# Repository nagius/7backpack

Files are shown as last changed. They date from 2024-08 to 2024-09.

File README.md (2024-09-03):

# 7Backpack

7Backpack is a shift register based led driver similar to [SparkFun Large Digit Driver](https://www.sparkfun.com/products/13279) but with a nicer form factor.

It has been designed to fit directly at the back of common anode 7-segments displays. Four sizes are supported : 1.5" (15101BS), 1.8" (18011BH), 2.3" (23011BH) and 3" (30101BS).

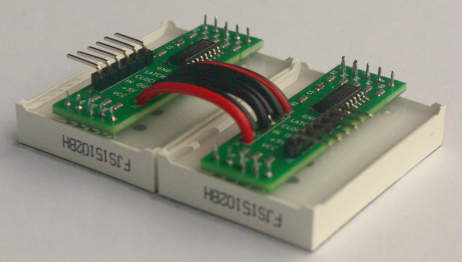
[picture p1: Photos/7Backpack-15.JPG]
1.5"
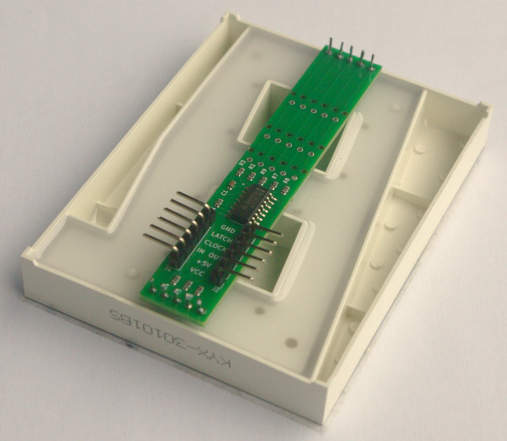
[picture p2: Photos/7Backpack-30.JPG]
3"
Board  

## Features

This board is functionnaly identical to SparkFun Large Digit Driver. Exact same code found at [Spakfun tutorial](https://learn.sparkfun.com/tutorials/large-digit-driver-hookup-guide/all) can be used without any modification.

The size of the board can be adjusted to match the size of the display. The PCB has pre-cut lines to snap unneeded pieces of the board.

## Manufacturing

See directory `Gerber/` for production files and bill of materials.

## License

Copyleft 2024 - Nicolas AGIUS

Creative Commons - Attribution-NonCommercial-ShareAlike 4.0 International (CC BY-NC-SA 4.0)

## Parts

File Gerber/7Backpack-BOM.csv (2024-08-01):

Comment | Designator | Footprint | LCSC
100nF | C1 | Capacitor_SMD:C_0603_1608Metric | C14663
10k | R1 | Resistor_SMD:R_0603_1608Metric | C25804
15 | R2,R3,R4,R5,R6,R7,R8 | Resistor_SMD:R_0603_1608Metric | C22810
2k | R9 | Resistor_SMD:R_0603_1608Metric | C22975
TPIC6C596DC | U1 | TPIC6C596DR:SOIC127P600X175-16N | C2872253

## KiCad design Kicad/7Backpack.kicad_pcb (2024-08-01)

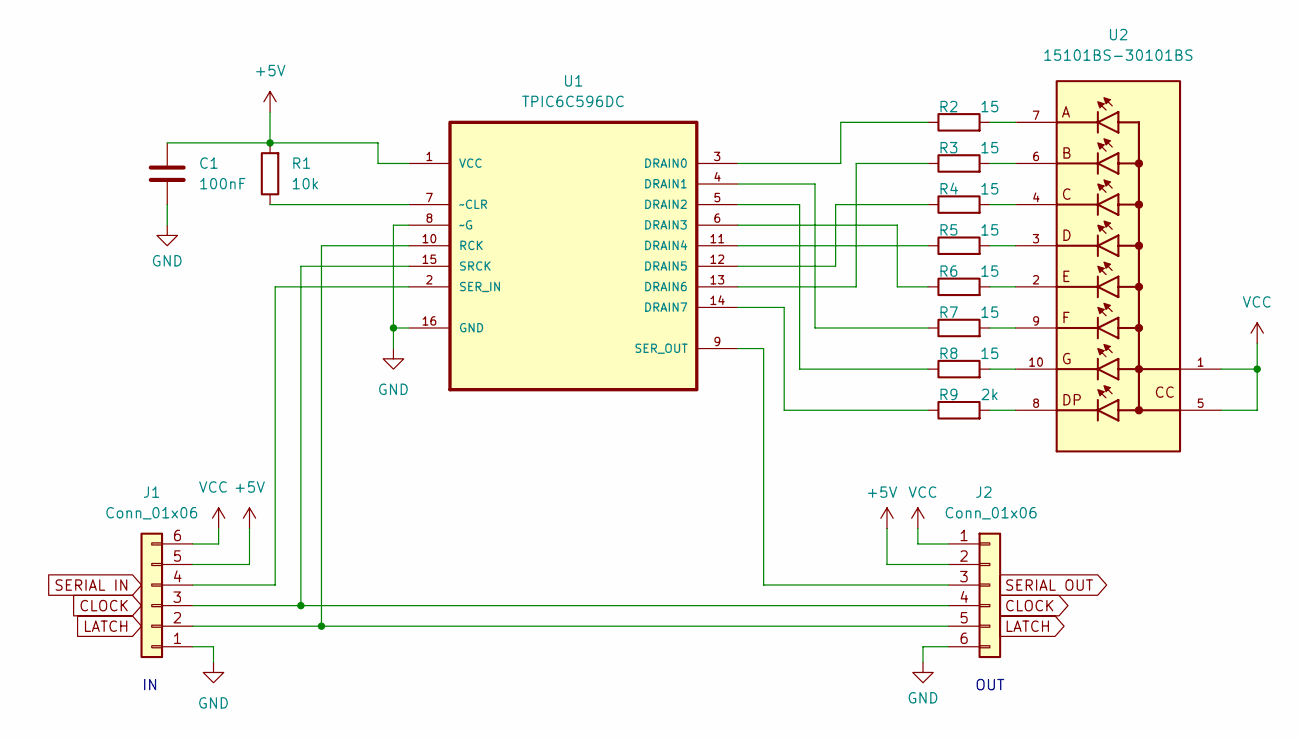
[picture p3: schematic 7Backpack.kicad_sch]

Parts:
C1: 100nF; C_0603_1608Metric; LCSC C14663
J1, J2: Conn_01x06; PinHeader_1x06_P2.54mm_Vertical
R1: 10k; R_0603_1608Metric; LCSC C25804
R2, R3, R4, R5, R6, R7, R8: 15; R_0603_1608Metric; LCSC C22810
R9: 2k; R_0603_1608Metric; LCSC C22975
U1: TPIC6C596DC; SOIC127P600X175-16N; LCSC C2872253
U2: 15101BS-30101BS

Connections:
+5V: C1.1, J1.5, J2.2, R1.2, U1.1 (VCC)
GND: C1.2, J1.1, J2.6, U1.8 (~G), U1.16 (GND)
unnamed: J1.2, J2.5, U1.10 (RCK)
unnamed: J1.3, J2.4, U1.15 (SRCK)
unnamed: J1.4, U1.2 (SER_IN)
unnamed: J2.3, U1.9 (SER_OUT)
unnamed: R1.1, U1.7 (~CLR)
unnamed: R2.1, U1.3 (DRAIN0)
unnamed: R2.2, U2.7
unnamed: R3.1, U1.13 (DRAIN6)
unnamed: R3.2, U2.6
unnamed: R4.1, U1.12 (DRAIN5)
unnamed: R4.2, U2.4
unnamed: R5.1, U1.11 (DRAIN4)
unnamed: R5.2, U2.3
unnamed: R6.1, U1.6 (DRAIN3)
unnamed: R6.2, U2.2
unnamed: R7.1, U1.4 (DRAIN1)
unnamed: R7.2, U2.9
unnamed: R8.1, U1.5 (DRAIN2)
unnamed: R8.2, U2.10
unnamed: R9.1, U1.14 (DRAIN7)
unnamed: R9.2, U2.8
VCC: J1.6, J2.1, U2.1, U2.5

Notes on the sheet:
OUT

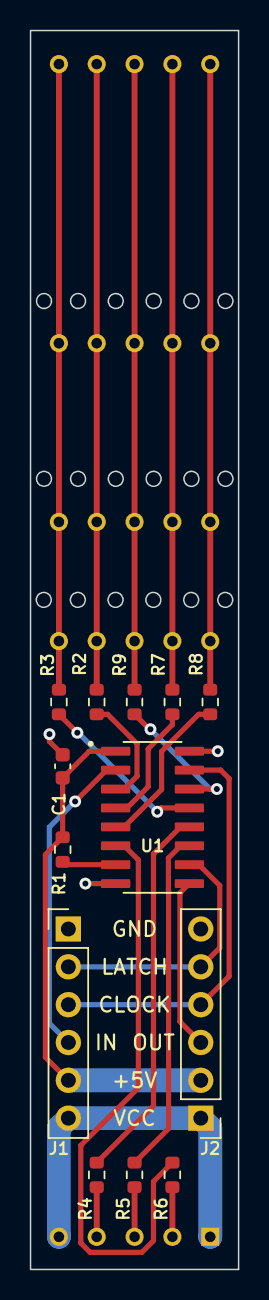
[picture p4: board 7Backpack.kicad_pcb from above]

Board: 2 copper layers, 14.0 x 83.2 mm, 14 parts (1 on the bottom side), 24 nets.

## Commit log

2024-07-21 Initial draft
    [7Backpack.kicad_pcb, 7Backpack.kicad_sch]
2024-07-21 Finalized routing
    [7Backpack.kicad_pcb]
2024-07-22 Updated silkscreen
    [7Backpack.kicad_pcb]
2024-07-22 Added pre-cut
    [7Backpack.kicad_pcb]
2024-07-31 AddedGerber files
    [7Backpack-BOM.csv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]
2024-08-01 Switched to SOP-16
    [7Backpack-BOM.csv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]
2024-09-03 Renamed directories
    [7Backpack.dsn, 7Backpack.kicad_pcb, 7Backpack.kicad_sch]
